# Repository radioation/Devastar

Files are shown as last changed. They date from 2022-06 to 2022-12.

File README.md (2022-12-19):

# Devastar
This project started as an attempt to create a flat-screen light-gun to work with a Sega Menacer game
I've been (*slowly*) writing.  I've since expanded it to work with other console and games.

This is still pretty early in develppment.  I'm not currently happy with the latency
and I think I can simplify the hardware side by moving to a different microcontroller. 
I expect many changes to occur before I make an official release.

**IMPORTANT:**  The circuits in this project are experimental.
I am *not* a practicing electrical engineer. The circuit diagrams here are what 
I've tested on my video game consoles.  The circuits work for me, but I'm not 
an expert at hardware design.  It's possible that I'm doing something incorrectly 
that may damage a console.  **USE THIS PROJECT AT YOUR OWN RISK**

## Sega Menacer Receiver
IR Menacer (https://www.youtube.com/watch?v=hTlZYFlo4qI)
## Atari XG-1 Receiver
IR Atari XG-1 (https://www.youtube.com/watch?v=NhuL7JiWjTw)
## Sega Light Phaser (SMS) Receiver
IR Phaser (https://www.youtube.com/watch?v=S2LcZB0aXFM)
## Sega Stunner (Saturn)  Receiver
Saturn/Virtua Gun backend (https://www.youtube.com/watch?v=gwXiiACAVe0)
## Nintendo SuperScope (SNES) Receiver
SuperScope Video (https://www.youtube.com/watch?v=DQ6kFDOmEEY)
## USB Mouse
USB Mouse Video (https://www.youtube.com/watch?v=n-yAgbNGrXw)

# License 
Most of the code I write are MIT licensed.  The Arduino files are LGPL.

Circuit diagrams are "CERN Open Hardware Licence Version 2 - Permissive"

# Faking a Sega Menacer

## X/Y Positioning
### Image Processing
I decided to try making a light-gun about 5 years ago because I had been 
working with ArUco markers for my Day Job.  My original idea was to create 
a PC based light-gun for use with my own software and emulators.  I was 
going to use ArUco markers to define the bounds of the display.

TODO: add info about
* ArUco Markers
* line along the edge of the display
* QR Code.  

### IR Detection
TODO: describe IR detection steps

## Menacer X/Y Positioning

### LM1881
The [LM1881 Sync Separator](https://www.ti.com/lit/ds/symlink/lm1881.pdf?ts=1666436908604) is used to 
detect the composite and vertical sync signals from a Sega Genesis.   I'm using the 
`Typical Connection Diagram` documented on the first page of the datasheet.  Pins 1 and 
3 are read by an Arduino Leonardo to simulate timing of a CRT scan

### Circuit
<coming soon~ish> 

### Timing
Setting the Menacer position means pulling the Genesis TH pin low at the appropriate time.  I can use
the output from a LM1881 sync separator to determine the current scan-line (Y) and wait (X) to
set the horizontal position on the scan-line.   A few experiments with a Genesis 
Model 2 and Arduino Leonardo gave me the following values:

* On-screen Y ranges from 30 to 250
* On-screen X ranges from 19 to 68 with delayMicrosecond().

With 68 - 19 = 49 steps, waiting X microseconds to set the horizontal position
seems insufficient.  I will try a faster microcontroller eventually, but right now I'm using
16MHz Arduino Leonardos.  

Sub-microsecond delay increments can be obtained with a custom delay function:
~~~
void delayX4Cycles(unsigned int c)
{
        if (--c == 0)
                return;

        // busy wait
        __asm__ __volatile__ (
                "1: sbiw %0,1" "\n\t" // 2 cycles
                "brne 1b" : "=w" (c) : "0" (c) // 2 cycles
        );
}
~~~

This gave me an on-screen X range of about 73 to 269 or 196 steps.  Which
is probably OK considering the resolution of the games.

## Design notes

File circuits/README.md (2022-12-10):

# LICENSE
The circuits here licensed under "CERN Open Hardware LIcense Version 2 - Permissive".
See "LICENSE-HARDWARE" in the main project folder.

# Disclaimer
I am *not* a practicing electrical engineer. The circuit diagrams here are what 
I've tested on my video game consoles.  The circuits work for me, but I'm not 
an expert at hardware design.  It's possible that I'm doing something incorrectly 
and may damage a console.  **USE THIS PROJECT AT YOUR OWN RISK**

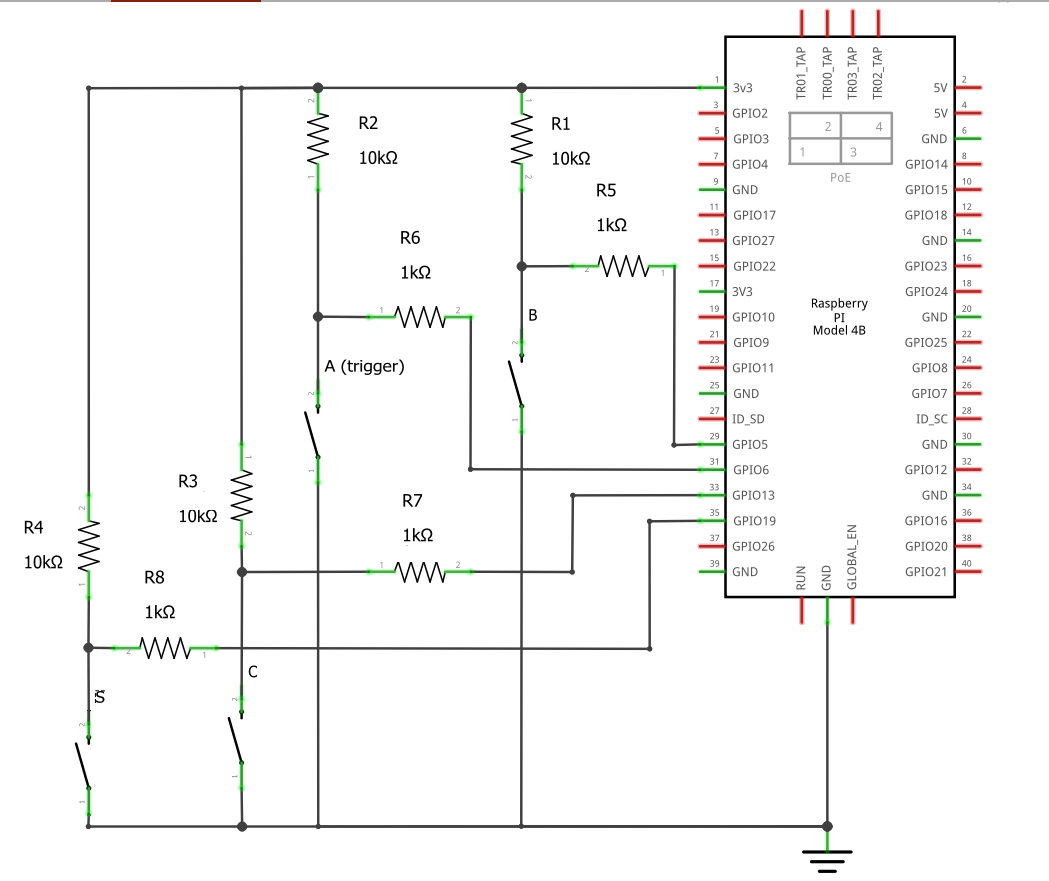
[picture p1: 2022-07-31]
images/lightgun_circuit.png

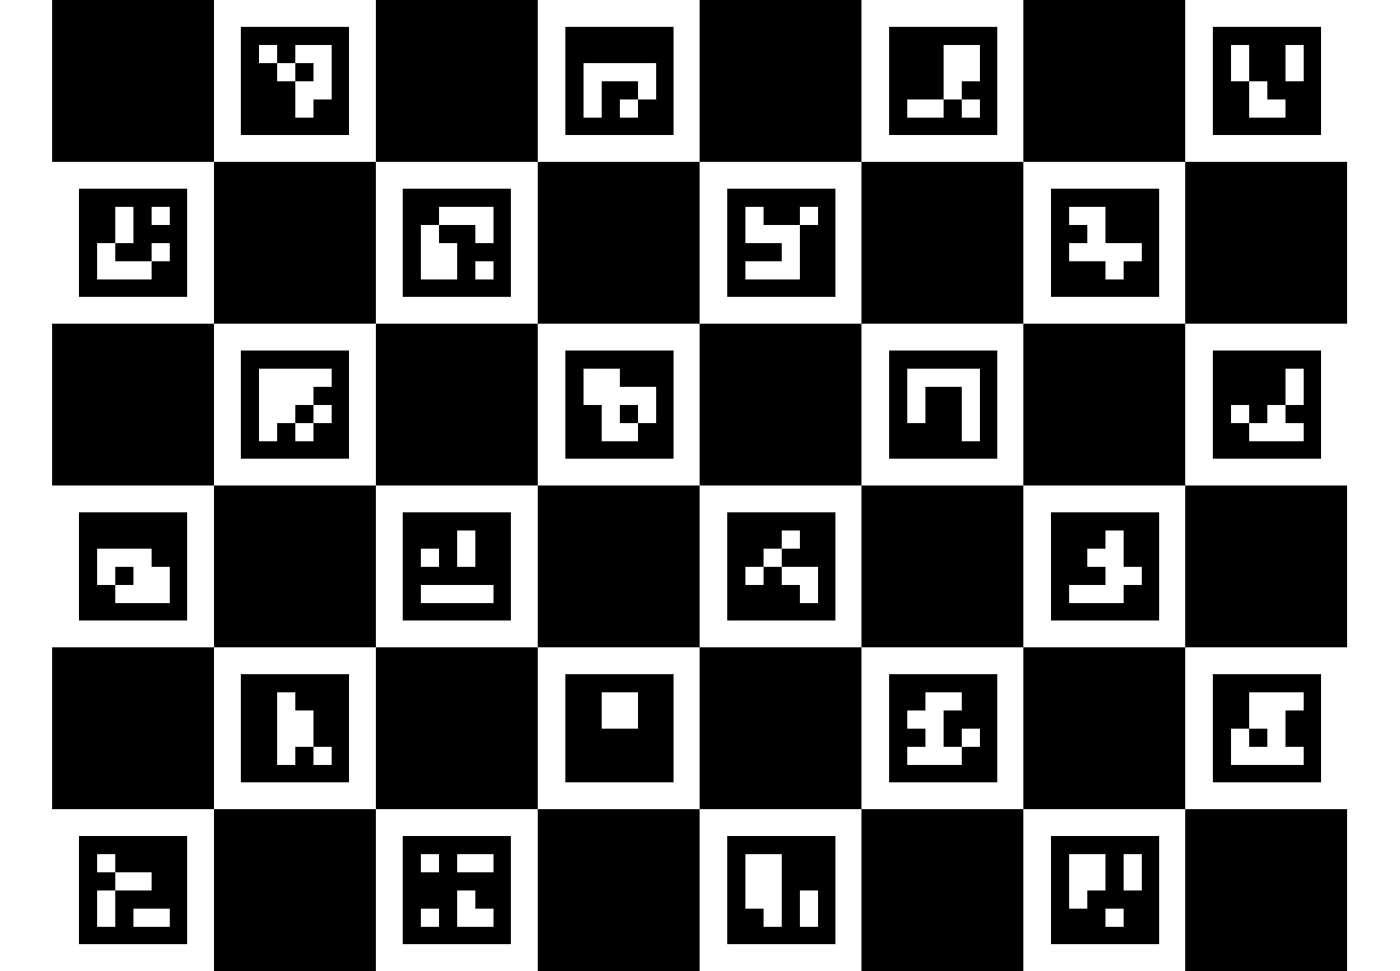
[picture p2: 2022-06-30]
images/board.png

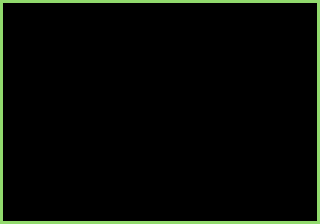
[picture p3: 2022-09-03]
util/justifier/res/bg/bg.png

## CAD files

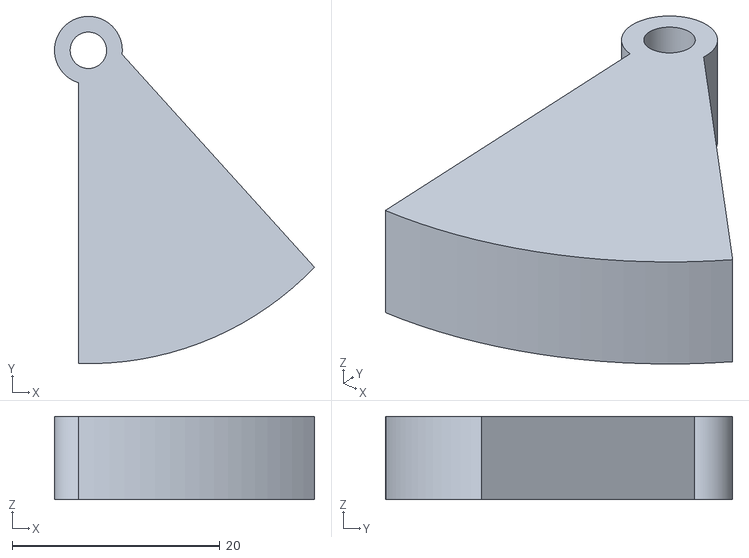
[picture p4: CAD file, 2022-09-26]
cad/gun/trigger.stl
25.0 x 33.4 x 8.00

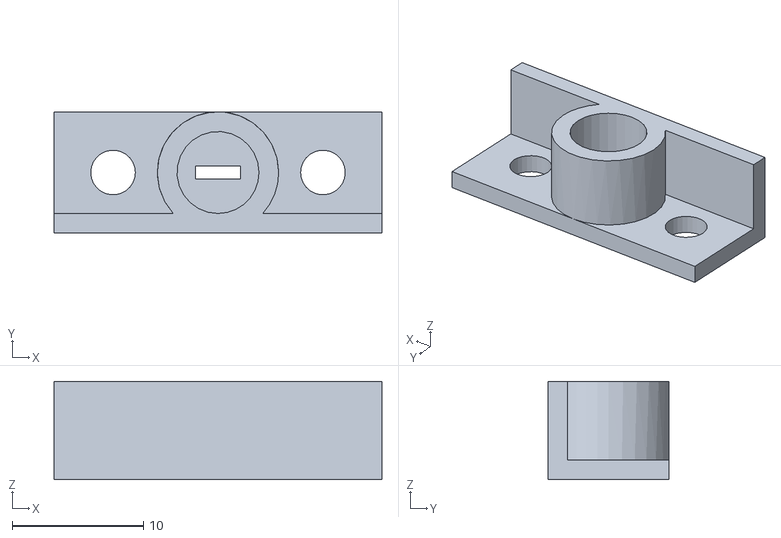
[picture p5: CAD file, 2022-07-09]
cad/IR/IR_EMITTER_TV_MOUNT-Body.stl
25.0 x 9.25 x 7.50

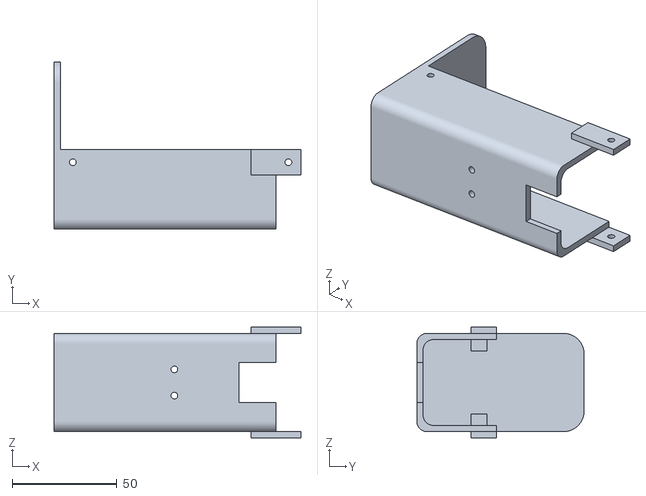
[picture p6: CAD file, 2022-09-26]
cad/gun/rear_barrel_bottom.stl
118.0 x 80.0 x 53.0

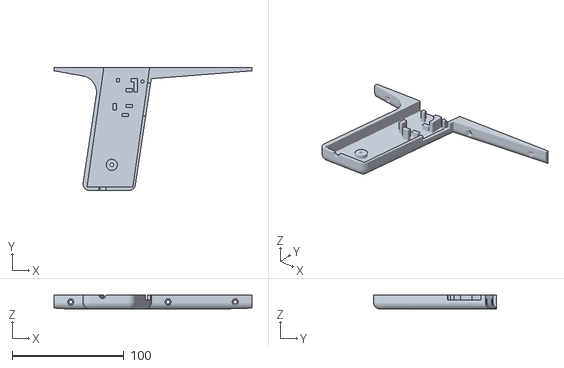
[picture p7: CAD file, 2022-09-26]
cad/gun/handle.stl
177.0 x 110.0 x 12.5

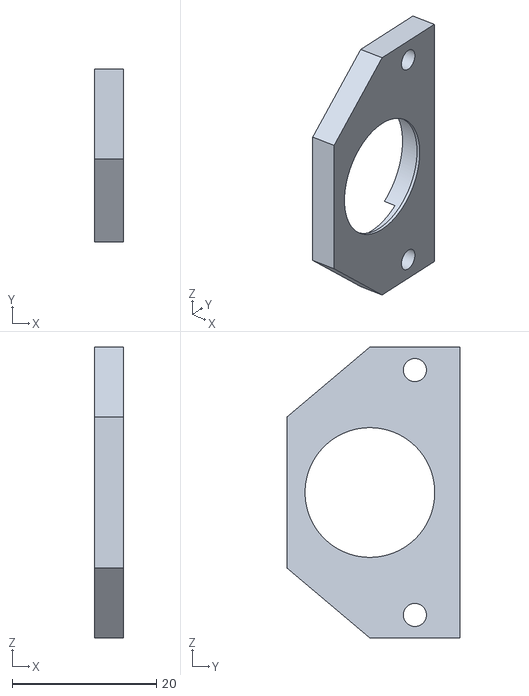
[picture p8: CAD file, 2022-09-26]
cad/gun/filter_plate.stl
4.00 x 24.0 x 40.4

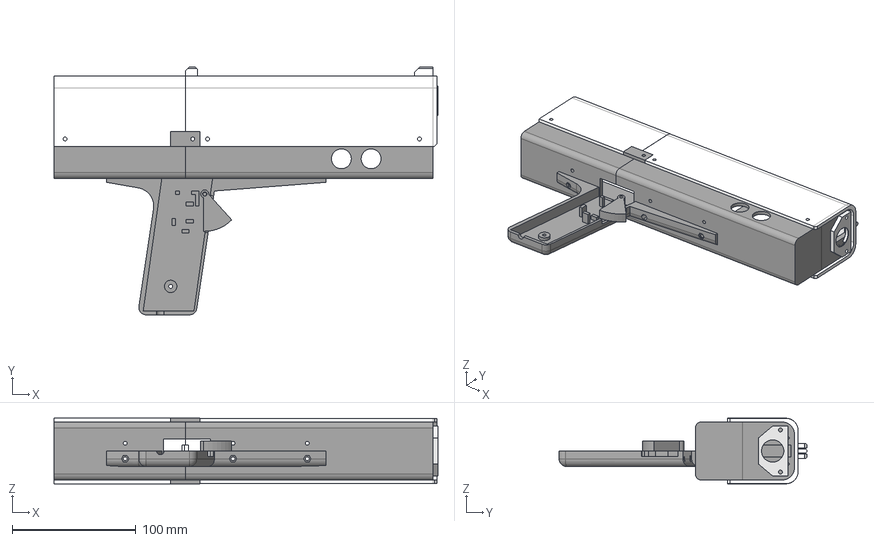
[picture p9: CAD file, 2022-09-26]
cad/gun/Devastar_body.FCStd
310.0 x 200.0 x 53.0 mm
Handle_V2
trigger
Barrel_V2
BarrelRear
BarrelTop
BarrelRearTop
filterPlate

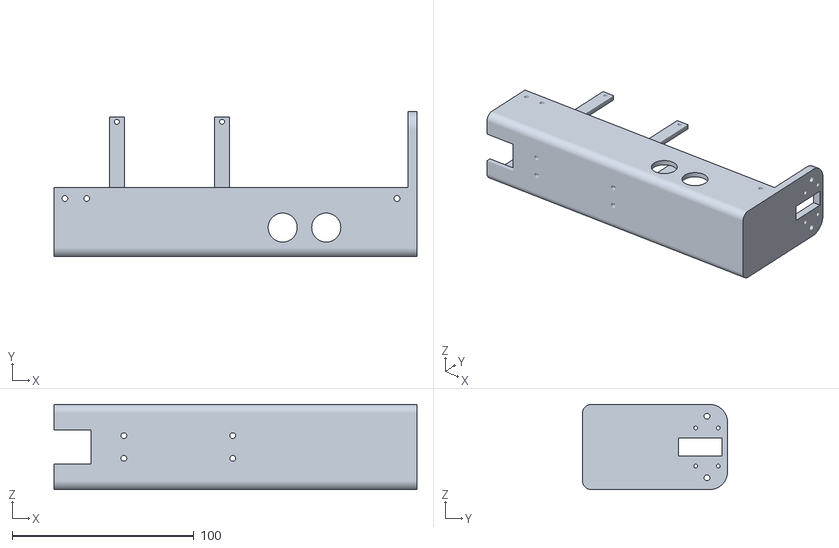
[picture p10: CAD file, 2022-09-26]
cad/gun/front_barrel_bottom.stl
200.0 x 80.0 x 47.0

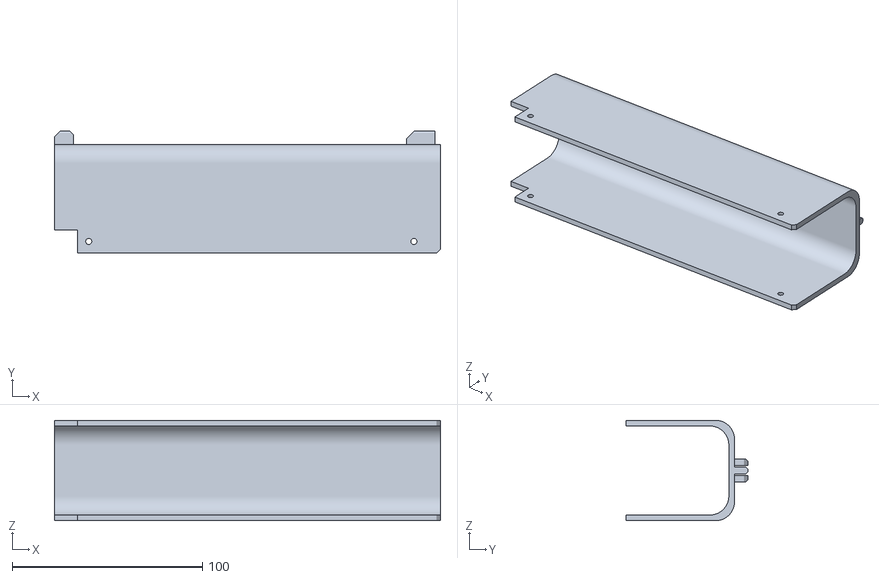
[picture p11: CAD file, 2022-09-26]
cad/gun/front_barrel_top.stl
203.0 x 64.0 x 52.8

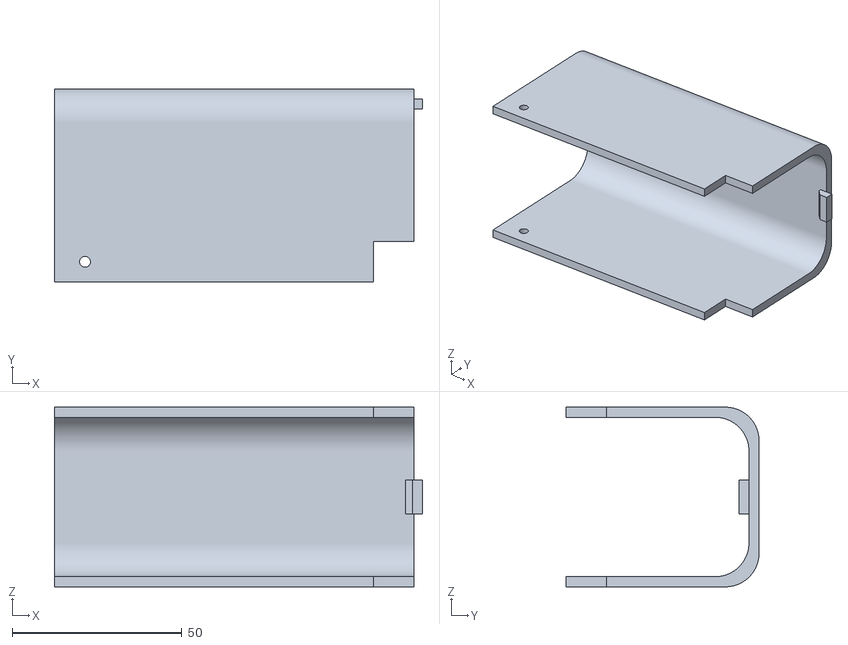
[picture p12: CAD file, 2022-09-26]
cad/gun/rear_barrel_top.stl
108.5 x 57.0 x 53.0

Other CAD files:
cad/IR/IR_EMITTER_TV_MOUNT.FCStd

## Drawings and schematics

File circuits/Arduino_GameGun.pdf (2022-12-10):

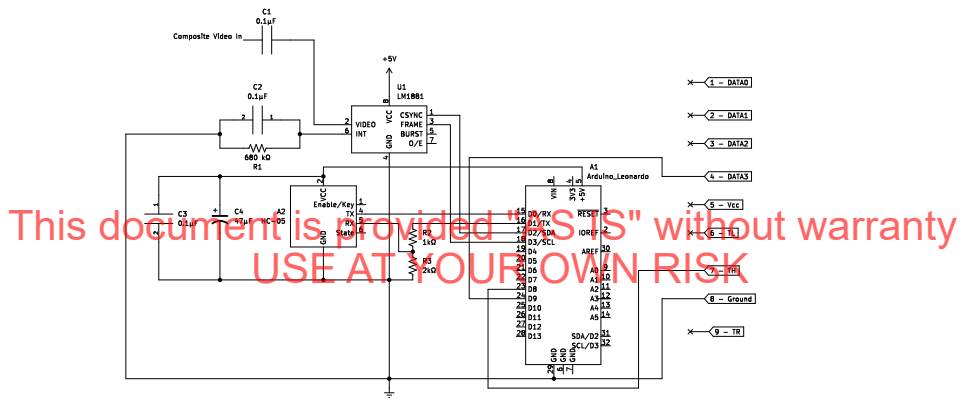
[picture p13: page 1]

This document is provided "AS IS" without warranty

USE AT YOUR OWN RISK

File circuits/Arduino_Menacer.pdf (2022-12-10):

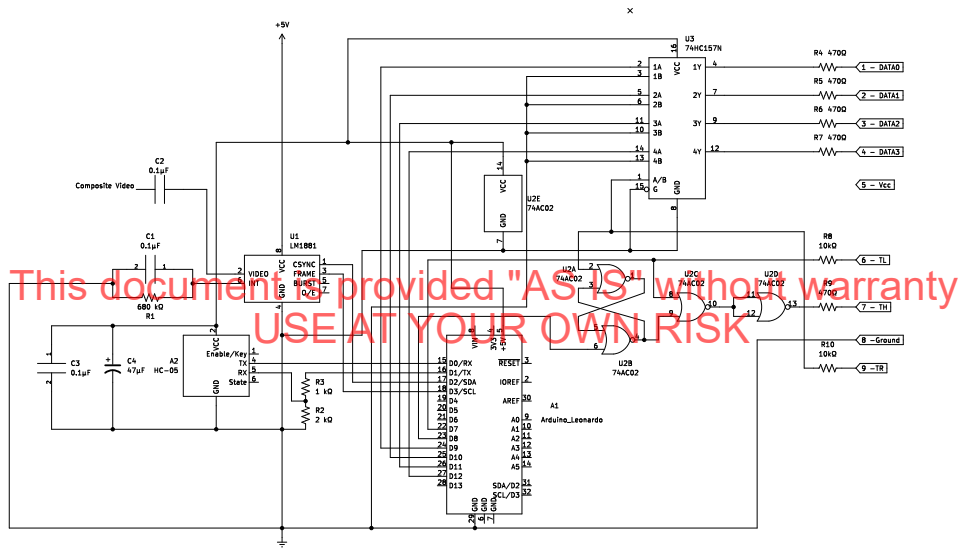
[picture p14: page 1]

This document is provided "AS IS" without warranty

USE AT YOUR OWN RISK

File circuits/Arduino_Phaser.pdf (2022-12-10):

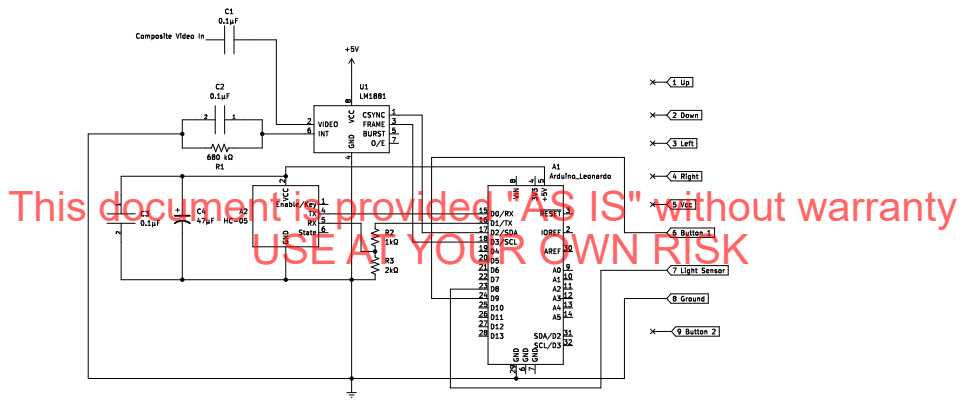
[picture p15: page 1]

This document is provided "AS IS" without warranty

USE AT YOUR OWN RISK

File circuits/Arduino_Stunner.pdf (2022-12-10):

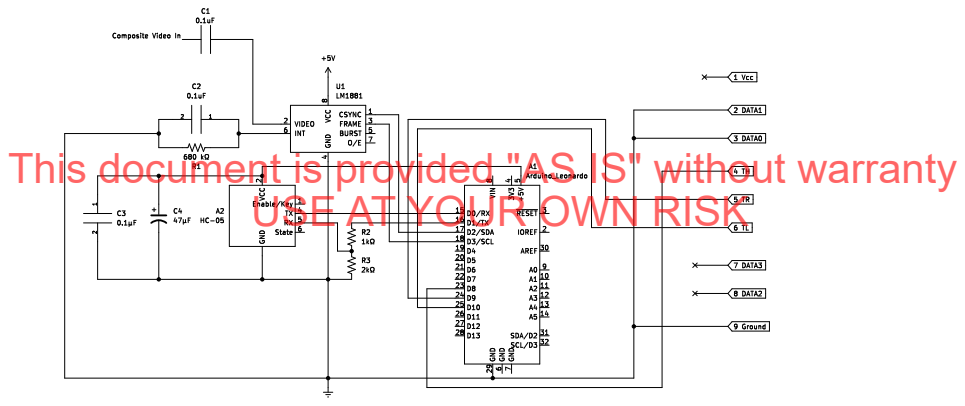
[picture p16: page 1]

This document is provided "AS IS" without warranty

USE AT YOUR OWN RISK

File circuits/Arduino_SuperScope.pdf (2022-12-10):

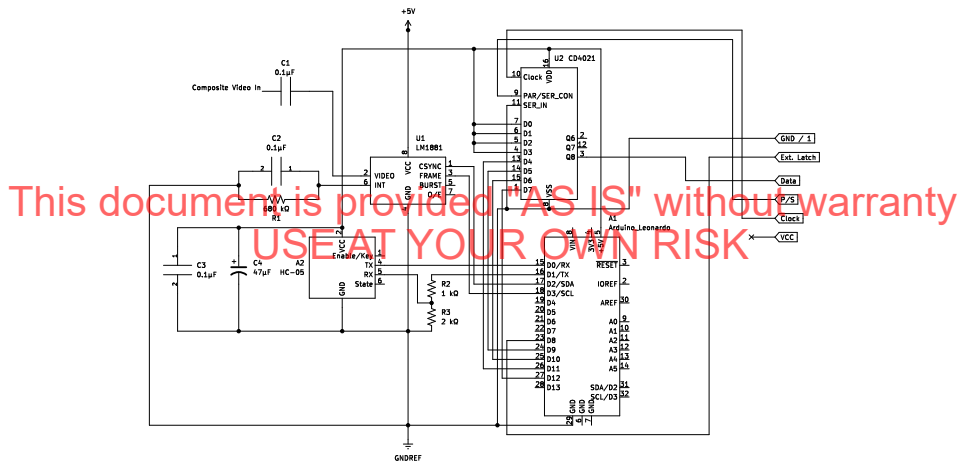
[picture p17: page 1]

This document is provided "AS IS" without warranty

USE AT YOUR OWN RISK

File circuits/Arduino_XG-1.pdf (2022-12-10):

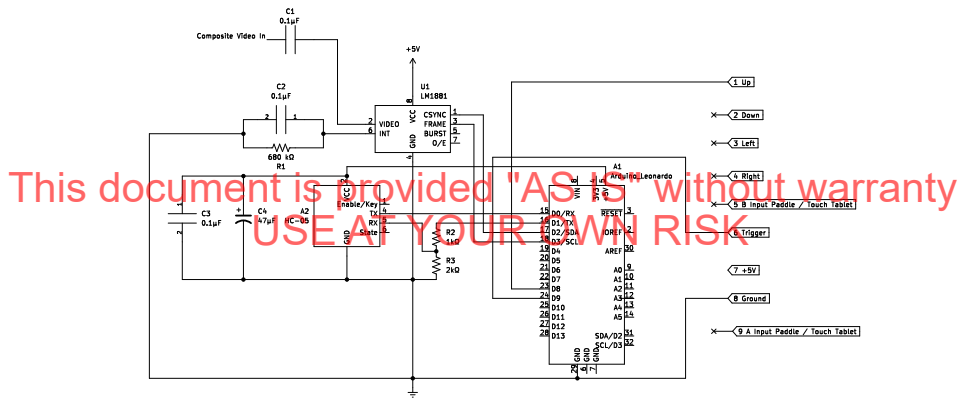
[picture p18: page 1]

This document is provided "AS IS" without warranty

USE AT YOUR OWN RISK

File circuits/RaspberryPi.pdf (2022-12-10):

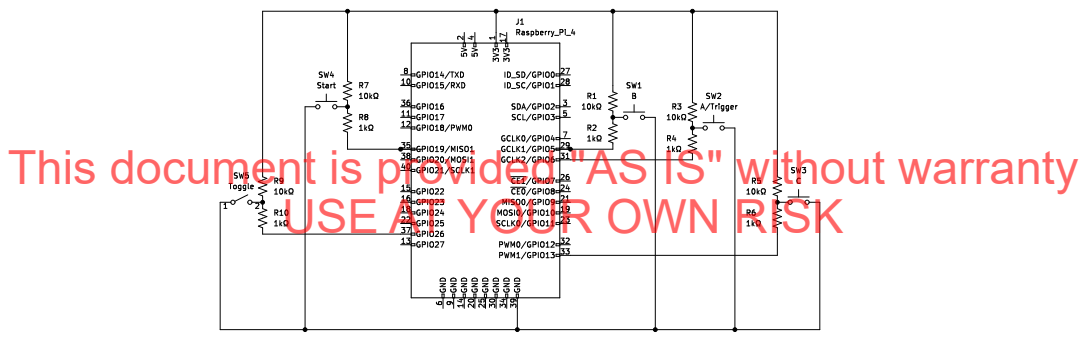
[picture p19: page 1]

This document is provided "AS IS" without warranty

USE AT YOUR OWN RISK

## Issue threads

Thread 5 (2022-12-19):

Improve Latency

radioation, 2022-12-19:
The current IR camera implementation latency is large.  Its somewhat tolerable (T2,  VirtuaCop)  in some games and unacceptable in others (Atari 8 bit).
* check timings of entire loop: frame acquisition, image processing, pose estimation, etc
* Look at other camera models if frame acquisition is unacceptably slow
* Look at optimizing or replacing image processing and pose estimation steps.

radioation, 2022-12-26:
[1f9b6d3](https://github.com/radioation/Devastar/commit/1f9b6d3598580145ecd5f62ed502be2282ddb70f)    Added code that uses cv::getPerspectiveTransform() to estimate intersection.  Results appear comparable to cv::solvePnP() but generally faster to compute.

radioation, 2022-12-26:
Reopening because I still need to look at other camera models and optimize or replace image processing stages.

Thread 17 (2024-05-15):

Ideas

mime29, 2024-05-15:
I love your lightgun projects.
Having a Saturn Stunner and looking at your project, I thought:
Would it be possible to get a replacement receiver for the stunner. It’s easy to open and should be easy to replace. That would allow people to enjoy the original hardware on new TVs!

Just another question:
The camera seems to be used inside your gun, detect the 4 IR lights positioned at the 4 tv screen corners, process the XY hit position and send them back to the Saturn with the proper timing. Isn’t it?
if that’s the case, if the tv has too much display lag. It means it won’t work isn’t it? What would be the max lag allowed in ms?
I’m asking because I use a frameister and this adds a bit of lag.

thanks.

radioation, 2025-03-31:
There's actually a number of sources of delay that I haven't really addressed yet. Display lag won't make the gun not work, but you'll see the changes a bit delayed. The best I can suggest for that is game mode and a fast converter. There are other sources of lag like image acquisition, image processing, and sending XY coordinates from the Pi to the controller. I'm going to try to address some of these when I get back to the project later this year.

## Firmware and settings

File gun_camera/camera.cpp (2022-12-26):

#include <opencv2/opencv.hpp>
#include <opencv2/aruco/charuco.hpp>
#include <opencv2/highgui/highgui.hpp>

#include <chrono>
#include <bitset>
#include <gpiod.h>

#include <experimental/string_view>

#include <iostream>
#include <vector>

#include <sys/types.h>
#include <sys/stat.h>
#include <stdio.h>
#include <stdlib.h>
#include <unistd.h>
#include <fcntl.h>
#include <termios.h>

#define BUFFER_SIZE 64
#define BAUDRATE B38400            

//#define SHOW_IMAGE
//#define SHOW_3D
//#define SHOW_CALC
//#define SHOW_TIME


#include <filesystem>
namespace fs = std::filesystem;

#include "compute.h"
#include "config.h"
#include "aim_calib.h"
#include "devastar_common.h"

#ifdef SHOW_3D
#include <GL/freeglut.h>
void init3d( const std::vector<cv::Point3f>& worldPoints );
void update3d( const cv::Mat& tvec, const cv::Mat& R, const float& u, const float& v  );
#endif





// Button variables 
struct gpiod_chip * g_chip;
struct gpiod_line_request_config g_config;
struct gpiod_line_bulk g_lines;

void gpio_cleanup() {
  gpiod_line_release_bulk( &g_lines );
  gpiod_chip_close( g_chip );
}


static void usage(const std::string& programName)
{
  std::cerr << "Usage: " << programName << " <options>"
    << "Options:\n"
    << "  -h,--help        Shows this help message\n"
    << "  -c,--calibrate   Run calibrate mode\n"
    << "  -o,--config_file Specify configuration file [config.yml]\n"
    << "  -a,--aim_file    Specify aim calibration file [aim_calib.yml]\n"
    << std::endl;
}


int main(int argc, char* argv[] )
{
  bool doCalibration = false;
  auto lastButton = devastar::BUTTON_NONE;
  std::string configFilename = "./config.yml";
  std::string aimCalibrationFilename = "./aim_calib.yml";

  for ( int i=1; i < argc; ++i ) {
    std::string arg = argv[i];
    if ((arg == "-h") || (arg == "--help")) {
      usage(argv[0]);
      return 0;
    } else if ((arg == "-c") || (arg == "--calibrate")) {
      doCalibration = true;
    } else if ((arg == "-o") || (arg == "--config_file")) {
      // must have a filename
      if (i + 1 < argc) { 
        configFilename = argv[++i];
      } else { 
        std::cerr << "--configuration requires a filename." << std::endl;
        return 1;
      }  
    } else if ((arg == "-a") || (arg == "--aim_file")) {
      // must have a filename
      if (i + 1 < argc) { 
        aimCalibrationFilename = argv[++i];
      } else { 
        std::cerr << "--aim_file requires a filename." << std::endl;
        return 1;
      }  
    } else {
      usage(argv[0]);
      return 0;
    }
  }

  // check configuration path
  fs::path configPath(configFilename);
  if( !fs::exists( configPath ) ) {
    std::cerr << "Configuration file '" << configFilename <<"' not found." << std::endl;
    return 1;
  }
  devastar::Configuration conf( configFilename );

  // from obvservation with delay4Cycles() on arduino
  // Menacer
  // X range is 69 to 263 : send 0 through 194
  // Y range is 26 to 247 : send 0 through 221
  // XG-1
  // X range is 40 to 237 : send 0 through 197
  // Y range is 21 to 210 : send 0 through 189
  // Sega Light Phaser
  // X range is 24 to 247 : send 0 through 223
  // Y range is 15 to 193 : send 0 through 178
  fs::path aimCalibrationPath(aimCalibrationFilename);

  devastar::AimCalibration ac;
  if( fs::exists( aimCalibrationPath ) ) {
    ac.readCalibrationFile( aimCalibrationPath );
  }
  devastar::AimCalibrator aimCalibrator(ac, 5, aimCalibrationFilename);

  std::cout << "Using: serial_device: " << conf.serialDevice << "\n";
  std::cout << "     ir_width: " << conf.irWidth << "\n";
  std::cout << "    ir_height: " << conf.irHeight << "\n";
  std::cout << " output_width: " << conf.outWidth << "\n";
  std::cout << "output_height: " << conf.outHeight << "\n";
  std::cout << " output_x_min: " << conf.outXMin << "\n";
  std::cout << " output_y_min: " << conf.outYMin << "\n";
  std::cout << "min_blob_size: " << conf.minBlobSize << "\n";
  std::cout << "max_blob_size: " << conf.maxBlobSize << "\n";
  std::cout << " ir_threshold: " << conf.irThreshold << "\n";
  std::cout << "  perspective: " << conf.usePerspectiveIntersection << "\n";

  std::cout << "        u_min: " << ac.uMin << "\n";
  std::cout << "        v_min: " << ac.vMin << "\n";
  std::cout << "        u_max: " << ac.uMax << "\n";
  std::cout << "        v_max: " << ac.vMax << "\n";
  std::cout << "    U/V width: " << ac.uWidth << "\n";
  std::cout << "   U/V height: " << ac.vHeight << "\n";

  bool use14BitData = conf.outWidth > 255.0f || conf.outHeight > 255.0f;
  std::cout << " use14BitData: " << use14BitData << "\n";

  // check calibration path
  fs::path calibPath("./calib.yml");
  if( !fs::exists( calibPath ) ) {
    std::cerr << "No camera intrinsics calibration file found.  Please run ./bin/camera_calibrate." << std::endl;
    return -1;
  }
  // setup GPIO 
  unsigned int offsets[5];
  int values[5];
  int gpioErr;
  g_chip = gpiod_chip_open("/dev/gpiochip0");
  if(!g_chip)
  {
    perror("gpiod_chip_open");
    return -1;
  }

  // setup button pins
  offsets[0] = 6;  // Trigger
  offsets[1] = 5;
  offsets[2] = 13;
  offsets[3] = 19; 
  offsets[4] = 26; 
  values[0] = -1;
  values[1] = -1;
  values[2] = -1;
  values[3] = -1;
  values[4] = -1;
  auto err = gpiod_chip_get_lines(g_chip, offsets, 5, &g_lines);
  if(err)
  {
    perror("gpiod_chip_get_lines");
    gpio_cleanup();
    return -2;
  }

  memset(&g_config, 0, sizeof(g_config));
  g_config.consumer = "devestar";
  g_config.request_type = GPIOD_LINE_REQUEST_DIRECTION_INPUT;
  g_config.flags = 0;

  // open lines for input
  err = gpiod_line_request_bulk(&g_lines, &g_config, values);
  if(err)
  {
    perror("gpiod_line_request_bulk");
    gpio_cleanup();
    return -3;
  }


  // Read in camera calibration calibration
  cv::FileStorage fileStorage(calibPath, cv::FileStorage::READ);
  cv::Mat cameraMatrix;
  cv::Mat distCoeffs;
  fileStorage["camera_matrix"] >> cameraMatrix;
  fileStorage["dist_coeffs"] >> distCoeffs;


  // setup videocapture
  cv::VideoCapture inputVideo;
  inputVideo.open(0);
  const int frameWidth = 640.0f;
  const int frameHeight = 480.0f;
  inputVideo.set(cv::CAP_PROP_FRAME_WIDTH, frameWidth);
  inputVideo.set(cv::CAP_PROP_FRAME_HEIGHT, frameHeight);
  std::cout << "CAP_PROP_BUFFERSIZE : " << inputVideo.set(cv::CAP_PROP_BUFFERSIZE,  1) << std::endl;


  // Setup World object points
  std::vector<cv::Point3f> worldPoints;
  worldPoints.push_back(cv::Point3f(0, 0, 0));
  worldPoints.push_back(cv::Point3f(conf.irWidth, 0, 0));
  worldPoints.push_back(cv::Point3f(0, conf.irHeight, 0));
  worldPoints.push_back(cv::Point3f(conf.irWidth, conf.irHeight, 0));

  // setup rectangle for PnP intersection 
  cv::Vec3f S1, S2, P0;
  P0[0] = worldPoints[0].x;
  P0[1] = worldPoints[0].y;
  P0[2] = worldPoints[0].z;

  S1[0] = worldPoints[1].x - P0[0];
  S1[1] = worldPoints[1].y - P0[1];
  S1[2] = worldPoints[1].z - P0[2];
  S1 = cv::normalize(S1);

  S2[0] = worldPoints[2].x - P0[0];
  S2[1] = worldPoints[2].y - P0[1];
  S2[2] = worldPoints[2].z - P0[2];
  S2 = cv::normalize(S2);

  // setup target verticies for prespective intersection
  std::vector<cv::Point2f> targetVertices =  {
    cv::Point(0, 0), 
    cv::Point(conf.irWidth - 1, 0),
    cv::Point(0, conf.irHeight - 1),
    cv::Point(conf.irWidth - 1, conf.irHeight - 1)
  };

#ifdef SHOW_3D
  glutInit(&argc, argv);
  init3d(worldPoints);
#endif

  // Set up Serial Configuration
  struct termios serial;
  char buffer[BUFFER_SIZE];
  bool serialPortReady = true;
  int fd = open( conf.serialDevice.c_str(), O_RDWR | O_NOCTTY | O_NDELAY);
  if( fd < 0 ) {
    std::cerr << "Unable to open serial" << std::endl;
    perror( conf.serialDevice.c_str() );
    serialPortReady = false;
  }
  auto result = tcgetattr( fd, & serial );
  if( result < 0 ) {
    std::cerr << "Unable to get serial attributes" << std::endl;
    serialPortReady = false;
  }

  cfmakeraw(&serial);

  serial.c_cflag |= (CLOCAL | CREAD);
  serial.c_iflag &= ~(IXOFF | IXANY);

  serial.c_cc[VMIN] = 0;
  serial.c_cc[VTIME] = 0;

  cfsetispeed(&serial, B9600);
  cfsetospeed(&serial, B9600);

  tcsetattr(fd, TCSANOW, &serial); // Apply configuration	

  // setup image processing variables
  std::vector<cv::Point2f> centers;
  centers.resize(4);
  cv::Mat frame;
  cv::Mat gray;
  cv::Mat thresh;
  cv::Mat displayCopy;
  std::vector<cv::Point2f> undistortCenters;
  auto noArray = cv::noArray();
  undistortCenters.resize(4);

  // screen center point
  std::vector<cv::Point2f> srcPoints(1);
  srcPoints[0].x = float(frameWidth/2);
  srcPoints[0].y = float(frameHeight/2);

  // setup output
  unsigned char offscreen[] = { 0xFF, 0xFF, 0x00 };
  //unsigned char offscreen16[] = { 0xFF, 0xFF, 0xFF, 0xFF, 0x00 };
  unsigned char xyb[3];  // 8 bits for x, y and buttons
  unsigned short sx, sy;
  unsigned char xxyyb[5]; // 14 bits for X and Y outputs. 7 bits for buttons
  unsigned char buttons = 0;

  // look at the cameras
  cv::Point2f pt;
  int ticks = 0;
  while (true) {
    ++ticks;
#ifdef SHOW_3D
    glutMainLoopEvent();
#endif
    // Process buttons
    buttons = 0;
#ifdef SHOW_TIME
    auto loopTopTime = std::chrono::steady_clock::now();
    auto startTime = std::chrono::steady_clock::now();
#endif
    err = gpiod_line_get_value_bulk(&g_lines, values);
#ifdef SHOW_TIME
    auto endTime = std::chrono::steady_clock::now();
    std::cout << "ELAPSED TIME>> frame gpiod_line_get_value_bulk(): " << float(std::chrono::duration_cast<std::chrono::microseconds>(endTime - startTime).count()) / 1000.0f << "\n"; 
#endif
    if(err)
    {
      perror("gpiod_line_get_value_bulk");
      gpio_cleanup();
      return -4;
    }

    if( !values[0] ) {
      buttons |= devastar::BUTTON_A;
    }
    if( !values[1] ) {
      buttons |= devastar::BUTTON_B;
    }
    if( !values[2] ) {
      buttons |= devastar::BUTTON_C;
    }
    if( !values[3] ) {
      buttons |= devastar::BUTTON_D;   // start button on menacer
    }
    if( !values[4] ) {
      buttons |= devastar::BUTTON_E;   // SWITCH
    }

    // Process Video from camera
#ifdef SHOW_TIME
    startTime = std::chrono::steady_clock::now();
#endif
    inputVideo >> frame;
#ifdef SHOW_TIME
    endTime = std::chrono::steady_clock::now();
    std::cout << "ELAPSED TIME>> frame grab: " << float(std::chrono::duration_cast<std::chrono::microseconds>(endTime - startTime).count()) / 1000.0f << "\n"; 
#endif
    // cv to grey
#ifdef SHOW_TIME
    startTime = std::chrono::steady_clock::now();
#endif
    cv::cvtColor( frame, gray, cv::COLOR_BGR2GRAY); 
#ifdef SHOW_TIME
    endTime = std::chrono::steady_clock::now();
    std::cout << "ELAPSED TIME>> cvtColor(): " << float(std::chrono::duration_cast<std::chrono::microseconds>(endTime - startTime).count()) / 1000.0f << "\n"; 
#endif

    // threshold on brightness
#ifdef SHOW_TIME
    startTime = std::chrono::steady_clock::now();
#endif
    cv::threshold( gray, thresh, conf.irThreshold, 255, cv::THRESH_BINARY);
#ifdef SHOW_TIME
    endTime = std::chrono::steady_clock::now();
    std::cout << "ELAPSED TIME>> cv::threshold(): " << float(std::chrono::duration_cast<std::chrono::microseconds>(endTime - startTime).count()) / 1000.0f << "\n"; 
#endif
    std::vector< std::vector< cv::Point> > contours;
    // look for IR lights
#ifdef SHOW_TIME
    startTime = std::chrono::steady_clock::now();
#endif
    cv::findContours( thresh, contours, cv::RETR_TREE, cv::CHAIN_APPROX_SIMPLE);
#ifdef SHOW_TIME
    endTime = std::chrono::steady_clock::now();
    std::cout << "ELAPSED TIME>> cv::findContours(): " << float(std::chrono::duration_cast<std::chrono::microseconds>(endTime - startTime).count()) / 1000.0f << "\n"; 
#endif

#ifdef SHOW_TIME
    startTime = std::chrono::steady_clock::now();
#endif
    float u = -1.0f, v = -1.0f;
    bool solveRet = false;
    // Look for screen intersection if we have at least 4 points
    if (contours.size() >= 4) {
#ifdef SHOW_TIME
      startTime = std::chrono::steady_clock::now();
#endif
      // compute moments to get centers.  
      std::vector< cv::Moments > moments( contours.size() );
      for( size_t i = 0; i < contours.size(); ++i ) {
        moments[i] = cv::moments( contours[i] );
      }

      int centerCount = 0;
      for( size_t i = 0; i < contours.size(); ++i ) {
        // using size cutoff to find 'good' candidates.  Look at other features like circularity, position, etc.
        if( moments[i].m00 > conf.minBlobSize && moments[i].m00 < conf.maxBlobSize ) {

          if( centerCount < 4 ) {
            centers[centerCount] = cv::Point2f( static_cast<float> ( moments[i].m10 / ( moments[i].m00 + 1e-5)), static_cast<float> ( moments[i].m01 / ( moments[i].m00 + 1e-5)) );

          }
          ++centerCount;

          if( centerCount == 4 ) {
            break;
          }
        }
      }

      bool hit = false;
      // only calculate hit if count is 4 (could potentially also check if "n >= 4", but 
      // use simplest case for now.
      if( centerCount == 4 ) {
#ifdef SHOW_TIME
        endTime = std::chrono::steady_clock::now();
        std::cout << "ELAPSED TIME>> get centers from moments: " << float(std::chrono::duration_cast<std::chrono::microseconds>(endTime - startTime).count()) / 1000.0f << "\n"; 
#endif


#ifdef SHOW_TIME
        startTime = std::chrono::steady_clock::now();
#endif
        size_t a=0;
        size_t b=1;
        size_t c=2;
        size_t d=3;
        size_t ab1, ab2, cd1,cd2;
        size_t i1, i2, i3, i4, m1, m2;

        // sort along X
        // split into 2 sets {a,b}  and {c,d}
        if( centers[a].x < centers[b].x ) {
          ab1 = a;
          ab2 = b;
        } else {
          ab1 = b;
          ab2 = a;
        }

        if( centers[c].x < centers[d].x ) {
          cd1 = c;
          cd2 = d;
        } else {
          cd1 = d;
          cd2 = c;
        }

        if( centers[ab1].x < centers[cd1].x ) {
          i1 = ab1;
          m1 = cd1;
        } else {
          i1 = cd1;
          m1 = ab1;
        }

        if( centers[ab2].x > centers[cd2].x ) {
          i4 = ab2;
          m2 = cd2;
        } else {
          i4 = cd2;
          m2 = ab2;
        }

        if( centers[m1].x < centers[m2].x ) {
          i2 = m1;
          i3 = m2;
        } else {
          i2 = m2;
          i3 = m1;
        }

        cv::Point2f pt1 = centers[i1];
        cv::Point2f pt2 = centers[i2];
        cv::Point2f pt3 = centers[i3];
        cv::Point2f pt4 = centers[i4];

        // compare higehts of first two and last two
        if( pt1.y < pt2.y ) {
          centers[0] = pt1;
          centers[2] = pt2;
        } else {
          centers[0] = pt2;
          centers[2] = pt1;
        }
        if( pt3.y < pt4.y ) {
          centers[1] = pt3;
          centers[3] = pt4;
        } else {
          centers[1] = pt4;
          centers[3] = pt3;
        }

#ifdef SHOW_TIME
        endTime = std::chrono::steady_clock::now();
        std::cout << "ELAPSED TIME>> sort centers: " << float(std::chrono::duration_cast<std::chrono::microseconds>(endTime - startTime).count()) / 1000.0f << "\n"; 
#endif


#ifdef SHOW_IMAGE
        // display it
        //cv::cvtColor( thresh, displayCopy, cv::COLOR_GRAY2BGR); 
        displayCopy = frame.clone();
        for( int i=0; i < centers.size(); ++ i ) {
          // draw point on image
          cv::Scalar color( 0,0,255 );
          if( i == 1 ) {
            color = cv::Scalar( 0,255,0 );
          } else if( i== 2 ) {
            color = cv::Scalar( 255,0,0 );
          } else if( i== 3 ) {
            color = cv::Scalar( 255,255,0 );
          }
          cv::circle( displayCopy, centers[i], 10.0f, color, 2.0f);
        }
        //cv::circle( displayCopy, pt, 5.0f, cv::Scalar(0,255,255), 3.0f);

        cv::imshow("points", displayCopy );
        cv::waitKey(1);
#endif

        // rvec- is the rotation vector
        // tvec- is the translation vector 
        float u,v;
        if(conf.usePerspectiveIntersection ) {
	  cv::undistortPoints( centers, undistortCenters, cameraMatrix, distCoeffs, noArray, cameraMatrix );
          getPerspectiveIntersection( undistortCenters, targetVertices, srcPoints, u, v );
          solveRet = true;
        } else  {

          cv::Mat rvec, tvec;
          std::vector< cv::Mat > rvecs, tvecs;	
	  solveRet = getPnPIntersection( worldPoints, centers, cameraMatrix, distCoeffs, P0, S1, S2, conf.irWidth, conf.irHeight, u, v);
#ifdef SHOW_3D
          update3d( tvec, R, u, v );
#endif
        }

        if( solveRet ) {
          hit = u > ac.uMin && u < ac.uMax && v > ac.vMin && v < ac.vMax;
          if( hit ) {
#ifdef SHOW_IMAGE
            cv::Point2f pt;
            pt.x = (u/conf.irWidth) * float(frameWidth);
            pt.y = (v/conf.irHeight) * float(frameHeight); 
            cv::circle( displayCopy, pt, 5.0f, cv::Scalar(0,255,255), 3.0f);
            cv::imshow("points", displayCopy );
            cv::waitKey(1);
#endif
            // arduino has the min/max values  We just need the X/Y range calculated from the percentage
            auto outX = int(( (u-ac.uMin) / ac.uWidth) * conf.outWidth);
            auto outY = int(( (v-ac.vMin) / ac.vHeight) * conf.outHeight);
            if( !use14BitData ) {
              xyb[0] = (unsigned char)outX;
              xyb[1] = (unsigned char)outY;
              xyb[2] = buttons;
              if(serialPortReady ) {
                auto ret = write( fd, xyb, sizeof(xyb) );
              }
            } else {
              /* mouse mode is 1080p for now.
               *
               *
               sx = (unsigned short)outX;
               sy = (unsigned short)outY;
               memcpy( xxyyb, &sx, sizeof( unsigned short ) ); 
               memcpy( xxyyb + sizeof(unsigned short) , &sy, sizeof( unsigned short ) ); 
               */
              // bit7 determines starting char. This allows 14 bit numbers.  
              //  * first byte gets 128 + lower 7 bits of X
              //  * second byte gets bits 8 through 14 of x
              //  * third byte gets lower 7 bits of X
              //  * fourth byte gets bits 8 through 14 of x
              //  * fift byte gets buttons
              xxyyb[0] = 0x80 | (outX & 0x7F);
              xxyyb[1] = ( outX  >> 7 ) & 0x7F;
              xxyyb[2] = outY & 0x7F;
              xxyyb[3] = ( outY  >> 7 ) & 0x7F;
              xxyyb[4] = buttons;
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

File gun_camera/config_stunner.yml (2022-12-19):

%YAML:1.0
---
serial_device: /dev/rfcomm0
ir_width: 510
ir_height: 260
output_width: 180
output_height: 213
output_x_min: 40
output_y_min: 1
min_blob_size: 1.75
max_blob_size: 250.0
ir_threshold: 100.0

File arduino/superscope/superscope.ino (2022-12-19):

// some of this code (delayX4Cycles() )  was derived from https://github.com/arduino
// SO it's LGPL 2.1
/*
  This library is free software; you can redistribute it and/or
  modify it under the terms of the GNU Lesser General Public
  License as published by the Free Software Foundation; either
  version 2.1 of the License, or (at your option) any later version.
  This library is distributed in the hope that it will be useful,
  but WITHOUT ANY WARRANTY; without even the implied warranty of
  MERCHANTABILITY or FITNESS FOR A PARTICULAR PURPOSE.
  See the GNU Lesser General Public License for more details.
  You should have received a copy of the GNU Lesser General Public
  License along with this library; if not, write to the Free Software
  Foundation, Inc., 51 Franklin St, Fifth Floor, Boston, MA  02110-1301  USA
*/

#define USE_BLUETOOTH_SERIAL

#ifdef USE_BLUETOOTH_SERIAL
// Leonardo Bluetooth use real TX/TR
#define SERIAL_COM Serial1
#else
// Use USB 
#define SERIAL_COM Serial
#endif


// sync variables
const int COMPOSITE_SYNC_1881 = 2;
const int VERTICAL_SYNC_1881 = 3;
volatile int verticalLine = 0;
 
// controller pins
const int SUPERSCOPE_PIN_2 = 8;  // External Latch on SNES port
const int IC4021_START_15 = 9;  // trigger goes to shifter chip pin 15
const int IC4021_TURBO_14 = 10;  // turbo goes to shifter chip pin 14
const int IC4021_PAUSE_13 = 11;  //  pause goes to shifter chip pin 13
const int IC4021_TRIGGER_12 = 12;  // start goes to shifter chip pin 12

// offsets
const int minY = 40; //   40~ish near top. ~260 is the bottom   (range ~220)
const int minX = 1;  //  1 is the left? seems odd.  183 is near the right  but disappears past that range ~182)


// input variables
volatile byte y = 90;  // line count
volatile byte x = 100;  // Simulate TH delay
byte buttons = 0;

// modified delayMicroseconds to use the smallest possible wait
// to increase horizontal resolution
void delayX4Cycles(unsigned int c)
{
  if (--c == 0)
    return;

  // busy wait
  __asm__ __volatile__ (
    "1: sbiw %0,1" "\n\t" // 2 cycles
    "brne 1b" : "=w" (c) : "0" (c) // 2 cycles
  );
}

void compositeSyncInterrrupt() {
  verticalLine++;  
  // apparently we need to have more than one line
  if ( verticalLine >= minY + y && verticalLine < minY + y + 8 ) {  
    delayX4Cycles(minX + x);
    digitalWrite( SUPERSCOPE_PIN_2, LOW ); // TH active is 0
    delayMicroseconds( 4 ); // arbitrary.
    digitalWrite( SUPERSCOPE_PIN_2, HIGH );
  }
}


void verticalSyncInterrrupt() {
  verticalLine = 0;
}

void setup() {
  // serial communication
  SERIAL_COM.begin(9600);

  // Sync Splitter
  pinMode(COMPOSITE_SYNC_1881, INPUT);
  pinMode(VERTICAL_SYNC_1881, INPUT);

  // controller pins 
  pinMode(SUPERSCOPE_PIN_2, OUTPUT);
  pinMode(IC4021_TRIGGER_12, OUTPUT);
  pinMode(IC4021_TURBO_14, OUTPUT); 
  pinMode(IC4021_PAUSE_13, OUTPUT);
  pinMode(IC4021_START_15, OUTPUT); 
  digitalWrite(SUPERSCOPE_PIN_2, HIGH);
  digitalWrite(IC4021_TRIGGER_12, HIGH);
  digitalWrite(IC4021_TURBO_14, HIGH);
  digitalWrite(IC4021_PAUSE_13, HIGH);
  digitalWrite(IC4021_START_15, HIGH);

  // interrupts
  attachInterrupt(digitalPinToInterrupt(COMPOSITE_SYNC_1881), compositeSyncInterrrupt, RISING);
  attachInterrupt(digitalPinToInterrupt(VERTICAL_SYNC_1881), verticalSyncInterrrupt, RISING);
}

void loop() {
  if (SERIAL_COM.available() > 2)
  {
    x = SERIAL_COM.read();
    y = SERIAL_COM.read();
    buttons = SERIAL_COM.read(); 
    // set buttons
    if ( buttons & 0x01 ) {
      digitalWrite(IC4021_TRIGGER_12, LOW);
    } else {
      digitalWrite(IC4021_TRIGGER_12, HIGH);
    }
    if ( buttons & 0x02 ) {
      digitalWrite(IC4021_PAUSE_13, LOW);
    } else {
      digitalWrite(IC4021_PAUSE_13, HIGH);
    }
    if ( buttons & 0x04 ) {
      digitalWrite(IC4021_PAUSE_13, LOW);
    } else {
      digitalWrite(IC4021_PAUSE_13, HIGH);
    }
    if ( buttons & 0x08 ) {
      digitalWrite(IC4021_START_15, LOW);
    } else {
      digitalWrite(IC4021_START_15, HIGH);
    }
  }
    if ( buttons & 0x10 ) {
      digitalWrite(IC4021_TURBO_14, LOW);
    } else {
      digitalWrite(IC4021_TURBO_14, HIGH);
    }

}

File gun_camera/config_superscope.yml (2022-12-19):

%YAML:1.0
---
serial_device: /dev/rfcomm0
ir_width: 510
ir_height: 260
output_width: 180
output_height: 220
output_x_min: 1
output_y_min: 40
min_blob_size: 1.75
max_blob_size: 250.0
ir_threshold: 100.0

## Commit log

2022-06-30 adding initial arduino code
2022-06-30 calibration target board
2022-06-30 adding calibration utils from inital tests
2022-06-30 working on calibration utility
2022-06-30 working on camera code
2022-07-01 working on camera
2022-07-02 adding custom timer to increase H-delay resolution
2022-07-07 working on opengl display. bug fix: unify camera capture sizes
    [camera.cpp]
2022-07-09 adding IR mount design files
    [IR_EMITTER_TV_MOUNT-Body.stl, IR_EMITTER_TV_MOUNT.FCStd]
2022-07-09 working on GPIO for menacer buttons
2022-07-09 buttons state now being sent with X/Y
2022-07-09 button state now being received with X/Y
2022-07-24 adding freecad and stl files for light gun
    [Devastar_Body-Body001.stl, Devastar_Body-Handle.stl, Devastar_Body_M-Handle (Mirror #1).stl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]
2022-07-24 adding subdir for IR cad files
    [IR_EMITTER_TV_MOUNT-Body.stl, IR_EMITTER_TV_MOUNT.FCStd]
2022-07-31 adding circuit diagram for lightgun switches
2022-08-07 renaming camera folder to gun_camera
2022-08-21 Updating Arduino code for Bluetooth communication.
2022-08-21 adding subfolders to arduino
2022-08-26 Bug fix: trigger is 0x02 button
    [xg1.ino]
2022-08-28 Removing lightgun pin from XG-1 trigger pull test.
2022-08-28 Starting SMS Phaser arduino receiver code
2022-09-04 breaking out aim calibration
2022-09-04 working on aim calibration
2022-09-04 working on buttons for aim calibration
2022-09-11 Adding keypress checks to set buttons and X/Y values
2022-09-12 adding more controls to the Sega Stunner Arduino test
2022-09-19 Fixing fire and start button to work with Super Scope 6 game.
    [lm1881_superscope_hv_sync_test.ino]
2022-09-25 Deleting old body STL and Freecad files.
    [Devastar_Body-Body001.stl, Devastar_Body-Handle.stl, Devastar_Body_M-Handle (Mirror #1).stl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]
2022-09-26 new version of gun body.
    [Devastar_body.FCStd, filter_plate.stl, front_barrel_bottom.stl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]
2022-10-09 Fixing comments in superscope test
    [lm1881_superscope_hv_sync_test.ino]
2022-10-09 Updating Menacer arduino code to match new circuit.
2022-10-22 adding circuit diagrams
2022-10-23 working on calibration ideas
2022-10-25 updating receiver circuits
2022-10-25 adding back the sort to stabilize the aim
    [camera.cpp]
2022-10-27 adding BUTTON_E. Trying calibration code
2022-11-03 fixing calibration button handling. removing arduino offset from x/y estimation
    [camera.cpp]
2022-12-04 working on calibration struct test
2022-12-05 working on calibration
2022-12-05 adding const values for camera frame width/height
2022-12-10 Minor tweaks to minY and button code
2022-12-17 adding buttons to mouse mode debug output
2022-12-18 Fixing stunner serial read. Now able to play Virtua Cop
    [stunner.ino]
2022-12-19 working on superscope
    [aim_calib.yml]
2022-12-19 Removing TL interrupt for now. Seems unnecessary
2022-12-19 Fixing button handling bugs.
    [superscope.ino]
2025-10-16 switching to GPL2
    There's no escaping the fact that I'll be using some code from libcamera.
